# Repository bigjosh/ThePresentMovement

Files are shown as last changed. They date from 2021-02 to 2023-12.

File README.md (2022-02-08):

# The Present Movement
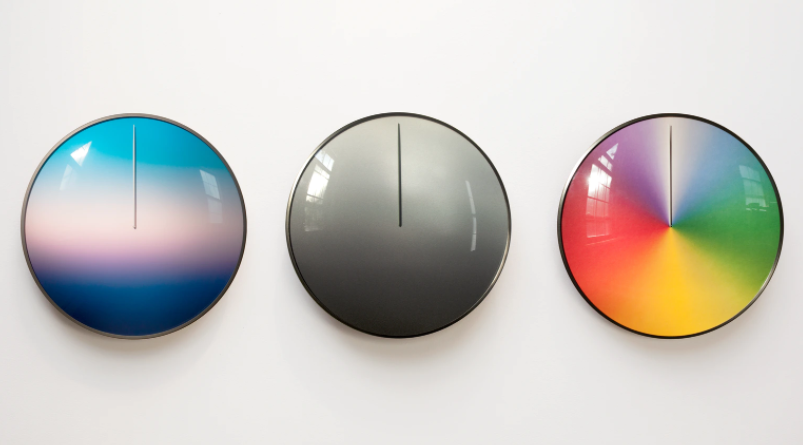
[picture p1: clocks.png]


 Movement for The Present clock from The Present. Kickstarter here...

https://www.kickstarter.com/projects/scottthrift/the-present-day-moon-year

## Features

* Uses proven existing UTS 24h mechanical gearbox gears and lavet motor 
* Can be software configured at programming time for 24h, lunar month, or year period
* Autoset feature lets user automatically move the hand to the correct time position when commissioned in the field 
* Uses a very accurate internal RX8900 real time clock (RTC) chip with temperature compensation that is good to +/-3ppm
* Uses cheap and common ATTINY25 microcontroller (MCU) chip
* Extremely low power - can run for decades or more on 2xAA batteries

## Usage

### Instating 

#### Day mode

Press the button when it is solar noon at the location where the clock will be used. The hand will make a full rotation to indicate that it is now set. For now on, the hand will indicate the current time of day where pointing up to the "noon" position is solar noon and pointing down is solar midnight.

#### Month and year mode

Press the button when you are ready to start using the clock. The hand will make a full rotation and then will continue to the current time. Since the time of lunar month and year are the same every where on Earth, no further input is required. Use in places with non-terran synodic periods is not supported in this version.

##### Southern hemisphere year model

A version of the clock with an inverted face is available on request for use below the equator. 
 
### Manual reset

Should the environment ever become out of sync with the clock hand and it is not possible to correct the environment, you can manually adjust clock hand position using the blue thumb-wheel to bring the two into agreement.  
 
## Theory of operation

### Gearbox 

#### Gearing

We start with a UTS gearbox that rotates an hour shaft once every 24 hours with a "step" once per second (86,400 steps per rotation). We remove the gear that drives the hour shaft and then we glue the now free hour shaft to the minute shaft. This results in an hour shaft that rotates once every 3600 steps. We connect our single hand to this combined hour-minute shaft.

This change in gearing reduces the number of ticks needed for a full rotation by 60 fold. This is good since ticks use power and make noise. This also means we can move to our autoset location 60x faster than we would have been able to if we had left the original gearing in place. 

The only real downside to this modification is reduced torque on the hours shaft, but since we know that the minute shaft must be strong enough to be able to rotate a minute hand, this is not a problem - especially since we no longer have to rotate the extra gears that would have also been driving the hours shaft.

#### Motor

The gearbox is driven by a lavet-type stepper motor. This motor is normally energized with a 1.5V signal across the leads for 50ms which causes the motor to rotate about 1/4 turn. When the coil is de-energized, the motor then rotates an additional 1/4 turn. The combination of these two phases results in a 1/2 turn "step" of the motor. The polarity of the 1.5V across the motor coil is reversed between each alternating step.    

### Ticking

Ticks are periodically generated by the RTC chip. This tick period is programmed into the RTC at start up by the MCU based on the set mode according to this table....

| Mode | 1 Tick every | Period for a 3600 step full rotation | 
| --- | --- | --- |
| Day | 24 seconds | 1 day |
| Moon | 11 minutes 48.734 seconds | 29.53059 days |
| Year | 2 hours 26 minutes 6 seconds | 365.25 days | 

Upon receiving a tick signal from the RTC, the MCU will...

1. Wake from deep low-power sleep
3. Energize the lavet coil (polarity alternates on each phase)
4. Sleep for 50ms to give the lavet rotor a chance to rotate to the intermediate position
5. Wake and de-energize the lavet coil and renable to pull-up
6. Go back to deep sleep to wait for the next tick

This cycle results in two movements of the lavet rotor which result in the hand moving 1/3600th of a rotation around the clock face. This step size is small enough that it is not visible to the naked eye.

#### Pull-up notes

We use the ~INT signal from the clock chip to transmit the ticks to the MCU. The clock chip can only pull this line low, so we use a pull-up resistor in the MCU to keep it high until the clock pulls it low. When the clock does pull it low, it holds it low for 7.813 ms and we can not control this time. To avoid wasting power though the pull-up during this period, we disable the pull-up for the first 16ms of the time when we are waiting for the motor to rotate.

We use the MCU's built-in watchdog timer to wake us up after this initial 16ms snooze, and then again 36ms later when it is time to de-energize the lavet coil. The watchdog timer only has a fixed number of possible timeouts so we picked these values to work around the fixed time periods of the ~INT signal and the lavet rotation. 

#### Polarity

The lavet motor is typically driven by alternating the polarity of a single 1.5V AA battery. We need 2xAA to give us >3V needed to run our chips (both require at least 1.8 volts to run reliably), so we connect one of the motor's leads to the midpoint between the two batteries. We then drive the other lead to either 0V or 3V using an MCU IO pin. This results in the motor seeing either +1.5V or -1.5V across its leads so it is happy. It also means that each battery is only driving the motor on every other step, which further extends battery life.

#### Full speed

The maximum speed the motor can reliably be driven at is 1 step every 100ms (each step consists of an energized and non-energized phase, each about 50ms). This means that it takes about 6 minutes for the hand to rotate all the way around the face at full speed (3600 steps * 100ms/step). We use the MCU's internal watchdog timer for timing these 50ms phases, and that timer is only accurate to +/-10% so the 6 minute time period is only approximate.      

### Autoset for Moon and Year modes

1. The current UTC time is stored in the MCU's EEPROM memory when it is initially programmed in the factory.
2. When it boots up initially after programming, it reads this time from the EEPROM and then uses it to set the RTC. 
3. The MCU then goes into deep sleep while waiting for a button press to wake it up. The RTC now continues to internally keep the current time as long as there is power.
4. When the button is pressed, the MCU wakes up and does a full speed victory lap around the clock face to indicate to give visual feedback to the user. This takes about 6 minutes. 
5. The MCU then sleeps until the next tick from the RTC. 
6. On waking, the MCU asks the RTC for the current UTC time. It uses this value to figure out where it is in the current 3600 step cycle around the clock face it should be
7. The MCU moves the hand to this location at full speed. Since it only takes 6 minutes to get to any hand position, and we know that moon and year ticks happen farther than 6 minutes apart, we do not need to account for time changes that happen while we are autoset positioning the hand.
8. Once the hand reaches the correct location, the MCU sleeps and waits for the next tick from the RTC to move the hand forward one tick. It repeats this until either the battery voltage drops to <1.6V or the heat death of the universe - which ever comes first.

### Autoset for Day modes

Since the hand position in day mode depends on the longitude where the clock happens to find itself on Earth, knowing the UTC time is of no use to us here. Therefore instead, we have the user press the button at solar noon. 

1. The user unpacks the clock and patiently waits until local solar noon. 
2. At the precise moment the sun crosses the meridian, the user anxiously presses the button.  
3. This wakes the MCU, which immediately reads the current UTC time from the RTC and then does a full-speed victory lap (as above) to give visual feedback, coming to rest again at the noon position on the face.
4. The MCU sleeps while it waits for a tick from the RTC (which will come within 24 seconds).
5. The MCU again reads the current time from the RTC and computes how many 1/3600th of a rotation steps are needed to bring the hand to the correct position.
6. The MCU steps the hand at full speed the the lesser of (1) the number of steps needed to get to the correct position, or (2) 200 steps. 
7. The MCU sleeps and waits for the next tick.
8. On waking, the MCU updates the target location forward 1 step and goes back to #6 to continue the race to catch up to the correct position. 

When the hand reaches the correct position, the clock goes into normal run mode where it moves the hand advances one step per tick forever and ever.

The reason we only do 200 steps per tick when trying to catch up is so that we never miss a tick which could give us an offset error. Even though the maximum offset error would be visually undetectable, it would still bother us.       

### Power usage

The ATTINY uses <0.1uA while sleeping and it spends the vast majority of its life sleeping (depending on mode). 

The RX8900 uses on average ~0.7uA at 3V.

Total constant current draw is ~1uA between ticks. 

Each tick additionally consumes an average of ~3.5mA over ~50ms, for a total of about 6.1mW. Remember that each tick only draws on one of the two batteries.  

#### Battery life estimates

##### Day

(1 rotation/day)/(3600 ticks/rotation) = 3600 ticks/day
(3600 ticks/day) * (365 days/year) = 1314000 ticks/year

(1314000 ticks/year) * (50 ms/tick) * (3.5 mA)

(2600 milli amp hour / battery)

(1uA constant draw)

Run time = ~35 years
 
https://frinklang.org/fsp/frink.fsp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

No point in doing the other modes since we are already way past where battery capacity is the limiting factor on lifetime!

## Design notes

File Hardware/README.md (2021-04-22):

# DayMoonYearMovement Hardware

This is the circuit board for the Present's [Day Moon Year Clock](https://www.kickstarter.com/projects/scottthrift/the-present-day-moon-year).

It is basically a brain transplant for an existing standard UCT 24h movement that drives with modes that take a day, a lunar month, or a year to cycle. 

To use this board, you must disassemble the original movement, remove the gear that links the hours and minutes shafts, and then glue those shafts together so that the hours shaft is now driven by the minutes gearing.

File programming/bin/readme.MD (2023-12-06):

# Programming instructions

## Prerequisites

You will need...

1. A windows computer
2. A `USBTiny` compatible programmer (like this [one](https://amzn.to/3AaaWSp))
3. A connector that fits the clock's 6-pin ISP programming port (like [this](https://amzn.to/3nE2BBh) or [this](https://www.sparkfun.com/products/11591))

Note that you can also use a non-Windows computer or a different programmer, but that would require a different procedure.   

## Setup

1. Copy the files from this directory onto the PC 
2. Plug in the programmer to a USB port on the PC
3. Make sure you hear the nice USB noise telling you the drivers installed OK
4. Make sure the little switch on the programmer board is set to `No Power`

## Procedure

1. Install batteries into clock.  
2. Install the hand pointing to 6 o'clock
2. Hold the connector against the clock board like this...

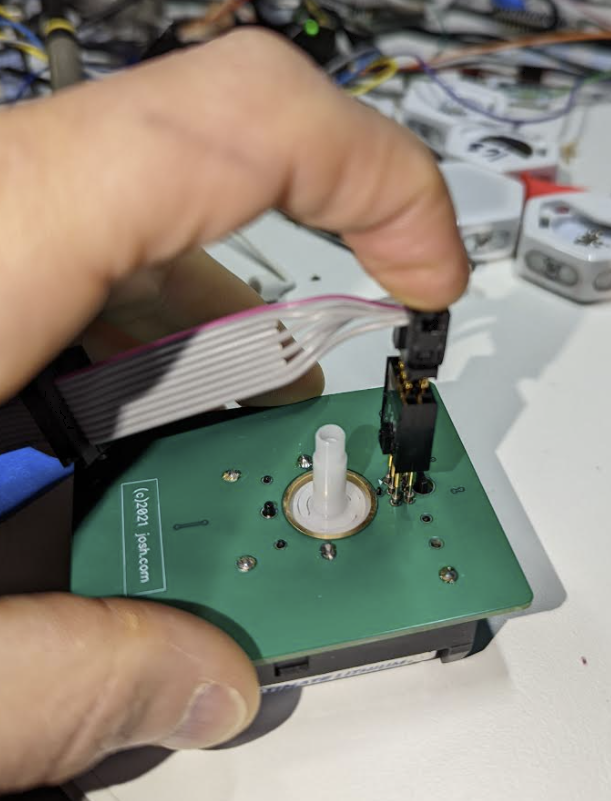
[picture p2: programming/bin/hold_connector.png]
    
1. Double click on the appropriate programming file in the directory (either `day.bat`, `moon.bat`, or `year.bat`)
2. Wait for programming success (see [Problems](#Problems) below if no success)
3. Remove programming connector
4. Push the button on the movement
5. Verify that the hand then rotates from 6 o'clock to noon position
6. Finished!

## Checking

Once the button has been pressed and the hand has completed its 1/2 revolution, the next button press will begin normal ticking. The clock should tick according to this schedule...

| Mode | Full Rotation Period | Tick Every... |
| - | - | - |
| Day | 24 hours | [24 seconds](https://www.wolframalpha.com/input/?i=%28%28day%29+%2F+3600%29+in+seconds) |
| Moon | 1 lunar month [(29.53059 days)](https://en.wikipedia.org/wiki/Lunar_month) | [11 minutes, 48.73411 seconds](https://www.wolframalpha.com/input/?i=%28%28lunar+month%29+%2F+3600%29+in+minutes) |
| Year | 1 solar year [(365.2422 days)](https://www.google.com/search?q=solar+year+in+days)| [2 hours 26 minutes](https://www.wolframalpha.com/input/?i=%28%28year%29+%2F+3600%29+in+minutes) |

## Problems

* Try again a couple of times. If you happen to be unlucky and a tick happens in the middle of the programming cycle that can interrupt the programming.
* Sometimes you need to unplug and replug the programmer into the USB port if the PC has gone to sleep since the last time you used it.
* Make sure all the pins from the programming connector are firmly touching the pads on the clock board.
* Make sure the programming connector is not backwards. The red stripe on the cable should line up with the little white arrow on the moment. 
* Make sure the clock has good batteries installed.
* Makes sure the little switch on the programmer is set to `NO POWER`.
* Try taking the batteries out for a minute and then putting them back in and then program again. Especially if the movement was last programmed in `hour.bat` or `spin.bat` mode since in this case there is likely to be a tick right in the middle of programming.  
* Try using `erase.bat` to quickly erase the chip and see if that works. After erasing, pull the batteries for a minute and then reinstall and try programming again.

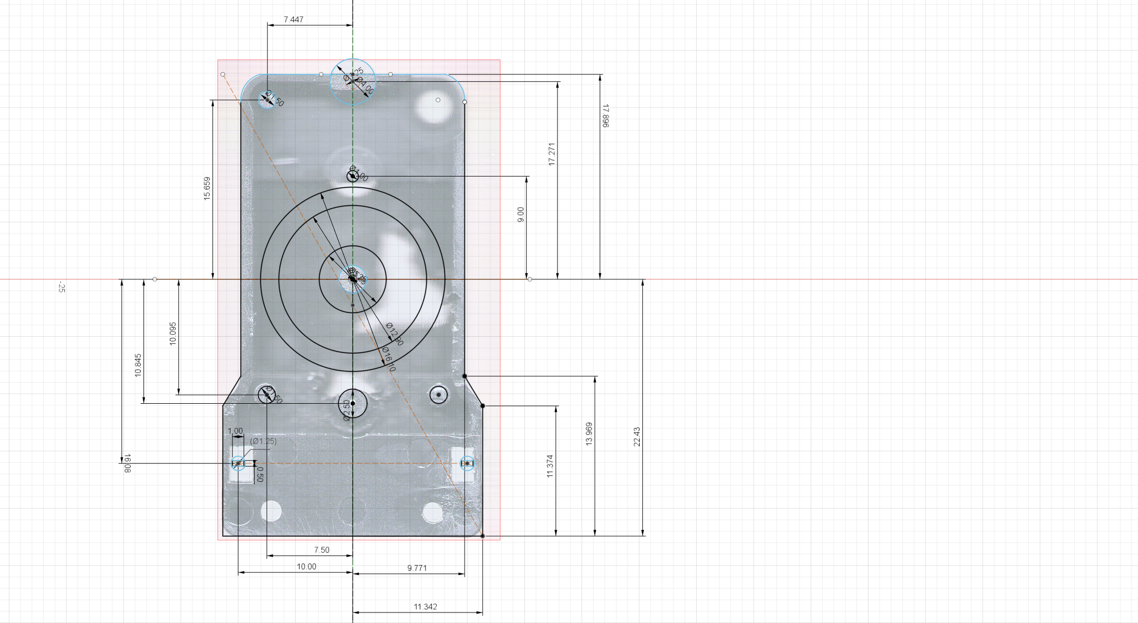
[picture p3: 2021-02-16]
Hardware/Movement demensions.png

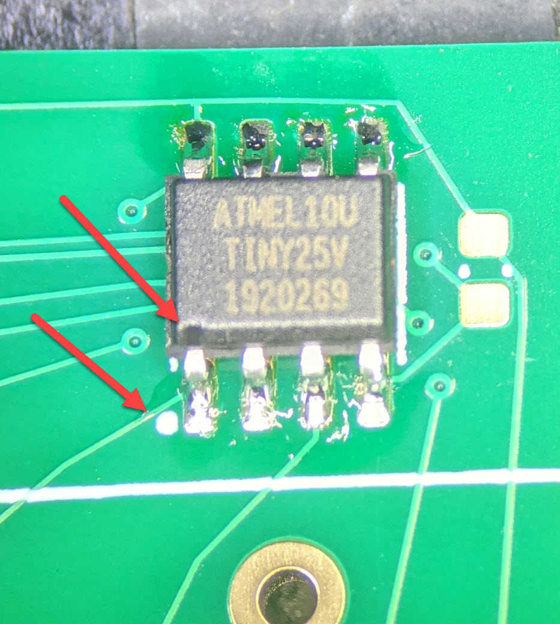
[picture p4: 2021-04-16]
Hardware/Orientation photos/U1 orientation.jpg

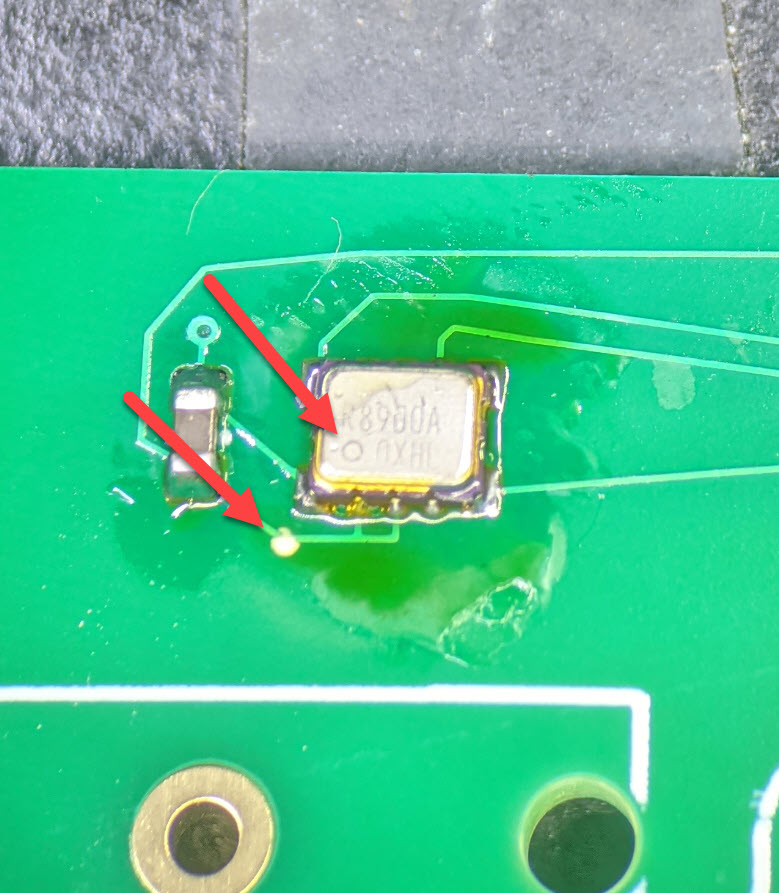
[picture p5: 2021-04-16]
Hardware/Orientation photos/U2 orientation.jpg

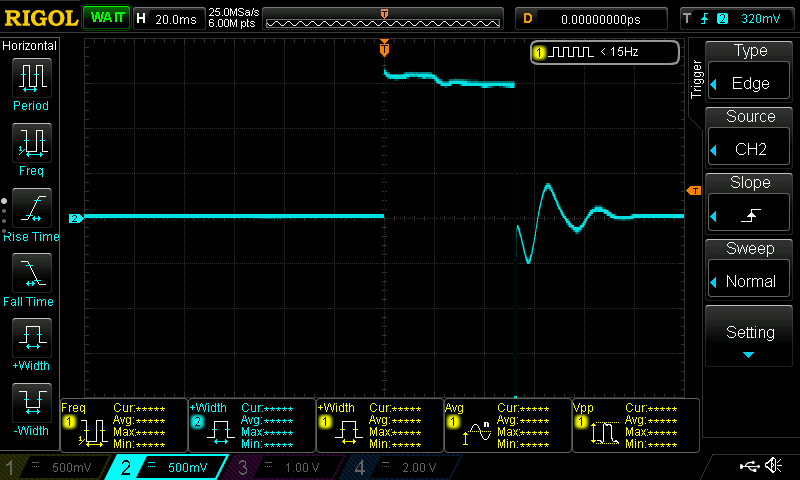
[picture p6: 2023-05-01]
waveforms/new-v-with-coil.png

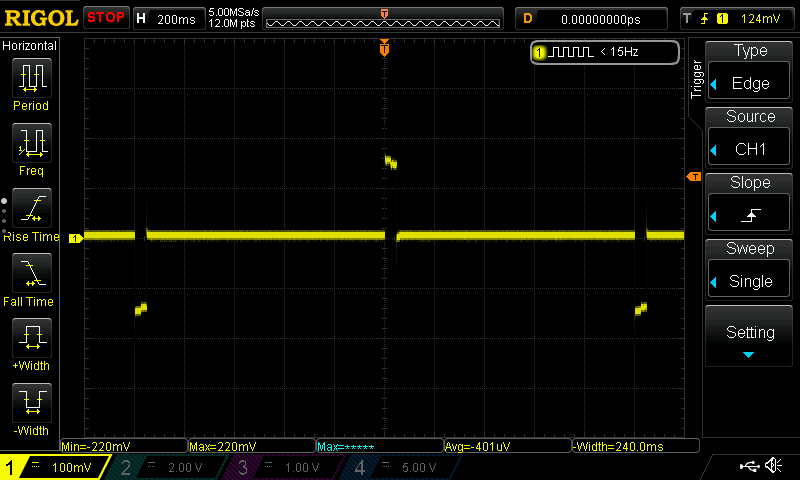
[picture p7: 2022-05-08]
waveforms/Original Movement across motor cycle.png

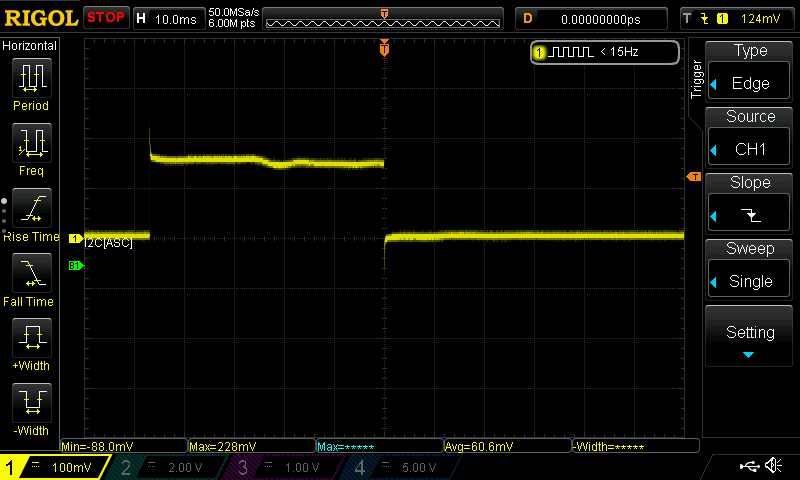
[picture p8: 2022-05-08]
waveforms/Original Movement across motor positive.png

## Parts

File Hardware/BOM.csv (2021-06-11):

# | RefDes | Quantity | Name
1 | BT1 | 1 | KeyStone1087
2 | BT2 | 1 | KeyStone1087
3 | C1 | 1 | C0603C105K3PACTU
4 | C2 | 1 | C0603C105K3PACTU
5 | J1 | 1 | ISP-6-NO-OUTLINE-ALL_ROUND
6 | L1 | 1 | Movement
7 | LOGO | 1 | Logo-Mask
8 | S1 | 1 | TL9320AF400QG
9 | U1 | 1 | ATTINY25-20SSUR
10 | U2 | 1 | RX8900-10SMD

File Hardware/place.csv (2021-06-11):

RefDes | Name | Pattern | Origin X (mm) | Origin Y (mm) | Side | Rotate | Value
BT1 | KeyStone1087 | KeyStone1087 | 19.75 | -11.73 | Top | 90.0
BT2 | KeyStone1087 | KeyStone1087 | -19.75 | -11.73 | Top | 270.0
C1 | C0603C105K3PACTU | CAP_0603_M | -20.32 | 22.86 | Top | 270.0 | 1uF
C2 | C0603C105K3PACTU | CAP_0603_M | 24.13 | 22.86 | Top | 270.0 | 1uF
J1 | ISP-6-NO-OUTLINE-ALL_ROUND | ISP-6-NO-OUTLINE-All-ROUND | 0 | 12.633 | Bottom | 180.0
L1 | Movement | Movement | 0 | 0 | Top | 0.0
LOGO | Logo-Mask | Logo-Mask | 0 | -28.133 | Top | 180.0
S1 | TL9320AF400QG | TL9320AF400QG | 0 | -37.104 | Top | 0.0
U1 | ATTINY25-20SSUR | SOIC8P127_489X599X175L83X41N | 19.75 | 22.86 | Top | 0.0
U2 | RX8900-10SMD | 10-SMD | -16.51 | 22.86 | Top | 90.0

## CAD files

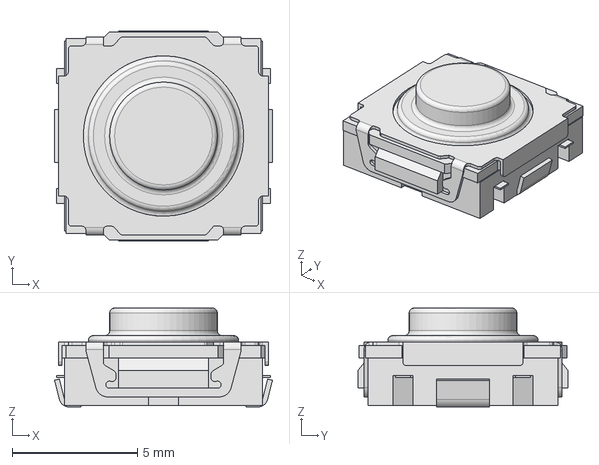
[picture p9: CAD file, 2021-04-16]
Hardware/DipTrace/3D models/TL9320AF400QG.stp
8.70 x 8.40 x 3.95 mm

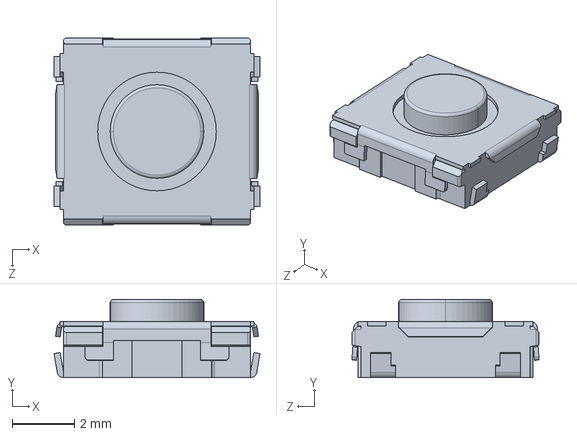
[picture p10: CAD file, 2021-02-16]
Hardware/DipTrace/3D models/EVQQ2-BFKPUY-02W.STEP
6.60 x 2.50 x 6.00 mm

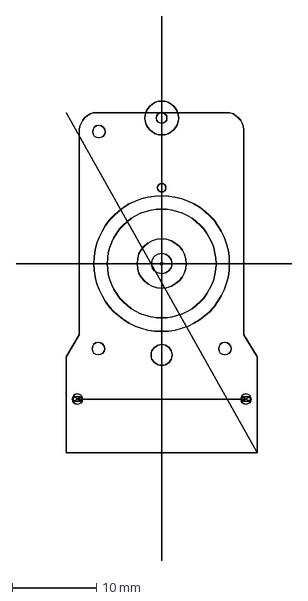
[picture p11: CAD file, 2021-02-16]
Hardware/Movement footprint.dxf
32.7 x 64.6 mm

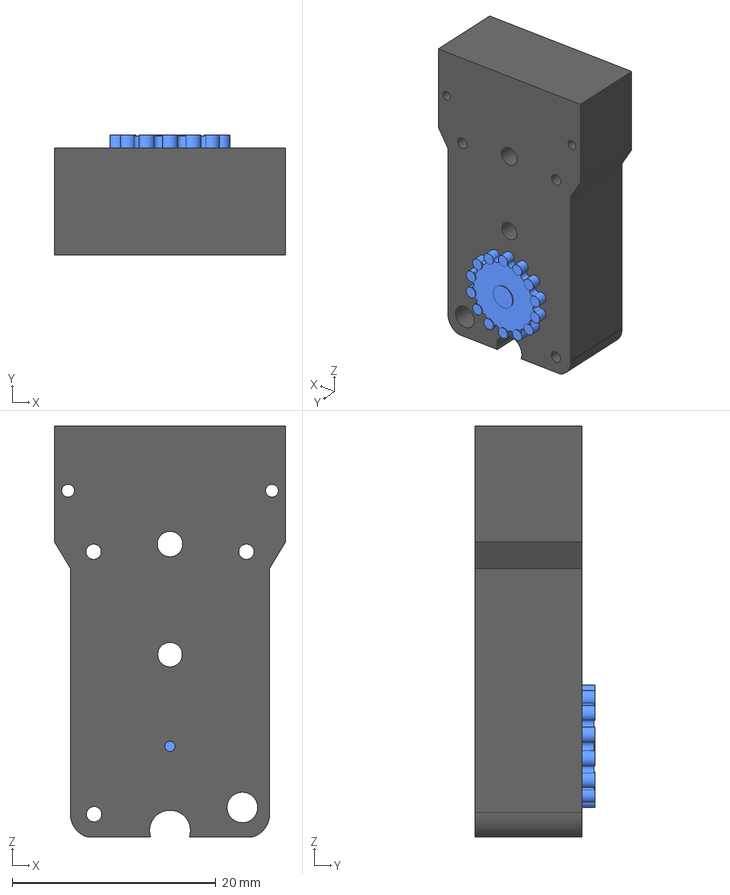
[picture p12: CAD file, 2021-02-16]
Hardware/DipTrace/3D models/Movement.step
22.7 x 11.8 x 40.3 mm

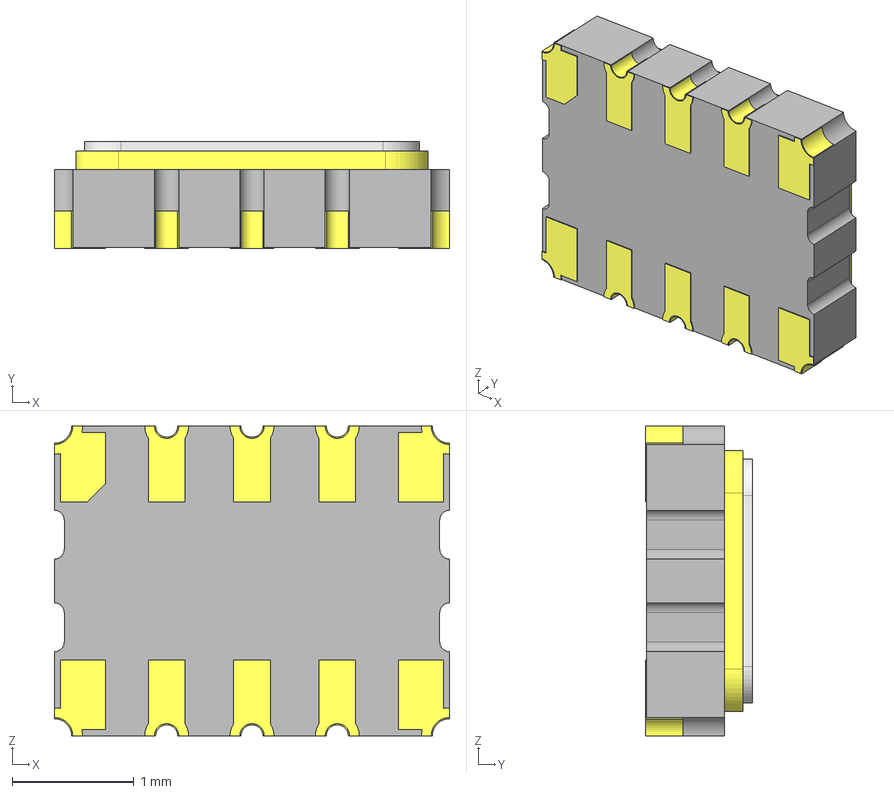
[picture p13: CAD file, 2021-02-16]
Hardware/DipTrace/3D models/RX8900-RA8900CE.stp
3.24 x 0.88 x 2.54 mm
CERAMIC_1_1_2
____-______O__1_6__1_1_2
____-______O__1_5__1_1_2
____-______O__1_10__1_1_2
____-______O__1_7__1_1_2
____-______O__1_3__1_1_2
____-______O__1_4__1_1_2
____-______O__1_1__1_1_2
____-______O__1_2__1_1_2
____-______O__1_9__1_1_2
____-______O__1_8__1_1_2
SRING_1_1_2
LID0001_1_1_2

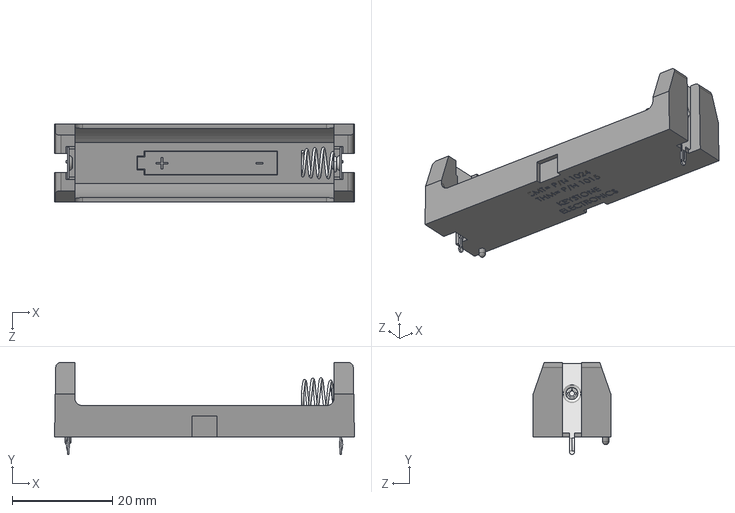
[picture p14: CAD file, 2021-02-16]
Hardware/DipTrace/3D models/keystone-PN1087.STEP
59.9 x 18.4 x 15.5 mm

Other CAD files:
Hardware/Present logo.dxf

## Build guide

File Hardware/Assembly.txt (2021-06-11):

Do place:
U1 
U2
C1
C2
S1

DO NOT PLACE:
BT1
BT2
J1
L1
LOGO

We will provide:
U1
U2

You will procure:
C1
C2
S1

OK TO SUBSTITUTE C1, C2 WITH SUITABLE CAP CER 1UF 25V X5R 0603

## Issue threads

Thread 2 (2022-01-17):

Do a Bresenham's style error track and adjust to cover cases when a rotation period is not exactly divisible by 3600

bigjosh, 2022-01-17:
This comes up with the lunar month which requires (2551443 seconds per rotation/3600 ticks per rotation) = 708.734166667 seconds per tick.

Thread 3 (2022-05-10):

Move /INT to a pin on the ATTINY that is not used in programming

bigjosh, 2022-05-10:
Currently if you get an /INT from the RX8900 in the middle of programming it can interrupt it. This is only a slight hassle since (1) only happens when reprogramming a unit that was already programmed with a short tick time, (2) you can just try again, or (3) you can always just pull the battery to reset the RX8900. But still, easy to completely avoid the issue.

bigjosh, 2023-05-06:
Switch pins with the button. This way, pushing the button will block programming but who cares.

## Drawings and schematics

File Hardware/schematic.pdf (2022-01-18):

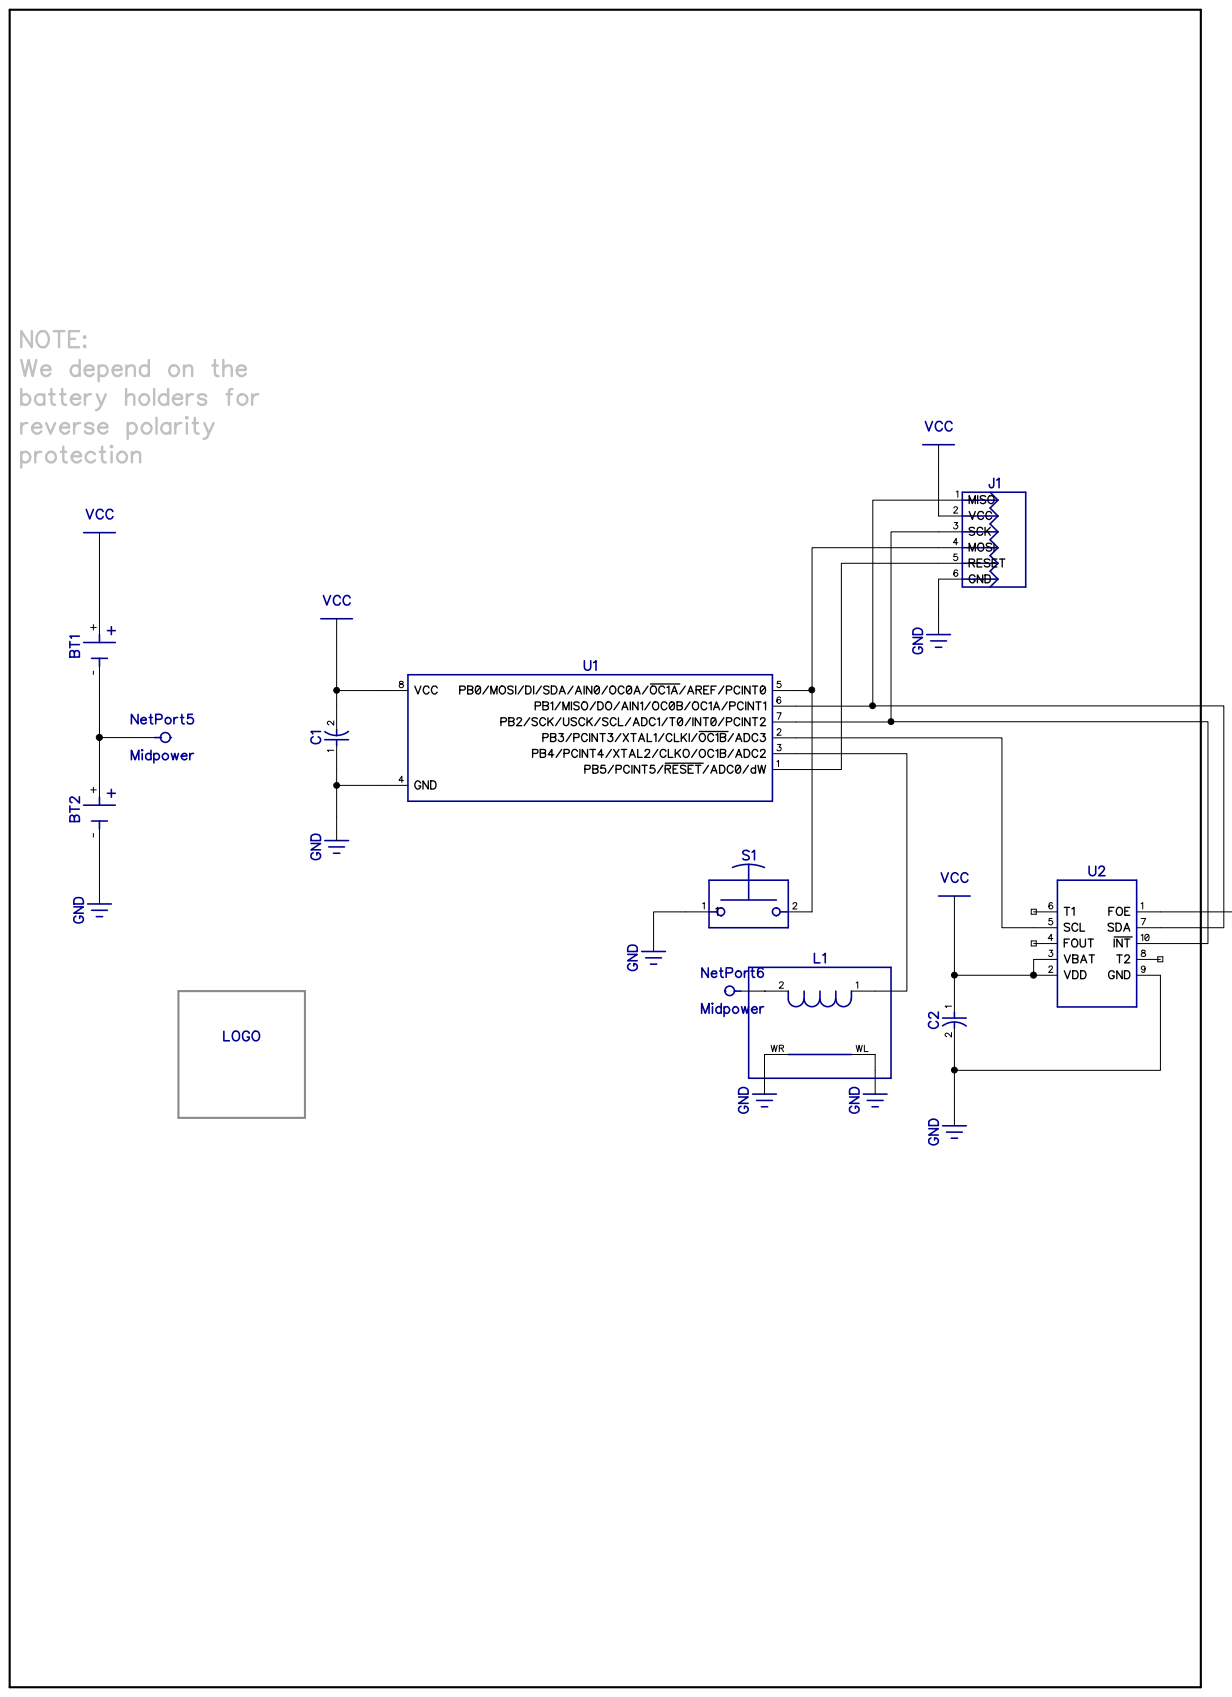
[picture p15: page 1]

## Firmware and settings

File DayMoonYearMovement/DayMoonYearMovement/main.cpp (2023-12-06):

/*
 * DayMoonYearMovement.cpp
 *
 * Created: 2/3/2021 12:04:26 AM
 * Author : josh
 */ 

// Note that this code uses a lambda so requires the "-std=c++11" in compiler options. :/


#include <avr/io.h>
#include <avr/sleep.h>
#include <avr/interrupt.h>
#include <avr/sfr_defs.h>		// _BV()

#include <assert.h>				// static_assert()

#include <avr/eeprom.h>


// Errormode looks like the hand twitching. Count the twitches to see which error.

#define ERRORMODE_COOKIE    2		// Magic cookie not found in EEPROM - EEPROM probably not properly programmed.
#define ERRORMODE_TIMEBASE	3		// If a bad timebase is specified in the EEPROM
#define ERRORMODE_BUTTON	4		// The button was stuck down at power-up

// We use the EEPROM to configure how the movement operates (ie which kind of clock it is in)

// What timebase to use for counting clicks? 
// NOTE: Use timebases < 1 second with care since the constant /INT signal will make it hard to 
// reprogram the unit since it shares the pin with the ISP.

// 0x00 = 4096 Hz - Once per 244.14 us
// 0x01 =   64 Hz - Once per 15.625 ms 
// 0x02 = "Second" update /Once per second 
// 0x03 = "Minute" update /Once per minute 

enum EEPROM_TIMEBASE {
	TB_4096THS	= 0x00,
	TB_64THS	= 0x01,
	TB_1S		= 0x02,
	TB_1M		= 0x03,	
};

const unsigned EEPROM_COOKIE = 0x4C4A;


// We add a magic cookie at the beginning of the EERPOM record so we know it was programmed.
// Could also be used later to version the record format

unsigned getCookieFromEEPROM() {
	
	return eeprom_read_word( (const uint16_t *) 0x0000 );
	
}


unsigned getTimebaseFromEEPROM() {
	
	return eeprom_read_word( (const uint16_t *) 0x0002 );
	
}

// How many clicks of the timebase per tick that gets sent to the MCU over the /INT line?

unsigned getCountFromEEPROM() {
	
	return eeprom_read_word( (const uint16_t *) 0x0004 );
	
}

// How many double ticks should we execute during the start-up button press?
// These ticks give visual feedback that the motor is working.
// We specify half the number of ticks we actually want so we know we always will land on phase A.

unsigned getStartDoubleTicksFromEEPROM() {
	return eeprom_read_word( (const uint16_t *) 0x0006 );		
}


// From the factory, the CLKDIV8 fuse is set, to we are only running at 1Mhz
// This will switch us to full speed 8Mhz, which is fine because we know we will have >3V from the 2xAA batteries. 

void fullSpeedClock() {
	CLKPR = (1<<CLKPCE); // Prescaler enable
	CLKPR = 0; // Clock division factor 1 (8Mhz)
}

void div8Clock() {
	CLKPR = (1<<CLKPCE); // Prescaler enable
	CLKPR = (1<<CLKPS1 || 1<<CLKPS0); // Clock division factor 8 (1Mhz)
}


#define F_CPU 8000000		// Assumes fullSpeedClock() above has been called to get rid of DIV8 that is normally set on power up. This must be defined before the inlcude of SoftI2C.

#include <util/delay.h>
#include <util/delay_basic.h>

#define SETBIT(x,b) ((x) |= _BV(b))
#define CLRBIT(x,b) ((x) &= ~_BV(b))
#define GETBIT(x,b) ((x) & _BV(b))


// *** Hardware connections

// Connections to the RTC (Epson RX8900)

#define RX8900_SCL_PORT PORTB
#define RX8900_SCL_DDR	DDRB
#define RX8900_SCL_BIT	3

#define RX8900_SDA_PORT PORTB
#define RX8900_SDA_DDR	DDRB
#define RX8900_SDA_BIT	1

#define RX8900INT_PORT		PORTB
#define RX8900INT_PIN		PINB
#define RX8900INT_DDR		DDRB
#define RX8900INT_BIT		2
#define RX8900INT_PCMSK		PCINT2

// Define these for the i2c code to see

#define SDA_PORT	RX8900_SDA_PORT
#define SDA_PIN		RX8900_SDA_BIT

#define SCL_PORT	RX8900_SCL_PORT
#define SCL_PIN		RX8900_SCL_BIT

#define	I2C_PULLUP		1					// Use internal pullups for the TWI lines
#define I2C_SLOWMODE	1					// No rush- we are using pullups so give time for them to pull up. 

// We use this not so great i2c code since it does not really matter - we only use it one time on power up and never touch it again
// so not worth rewriting. 

#include "SoftI2C.h"

// Connections to the movement windings (Lavet stepper motor)
// Note that this pin is connected to one end of the motor windings and the other end of the
// windings is connected to the midpoint between the two 1.5V batteries, so driving this pin high
// puts +1.5V on the winding and driving it low puts -1.5V across them. 

// TODO: Put the movement on pin AN0 or AN1 so we can disable the digital input buffer to 
// possibly save power when pin is floating midpoint. 

#define MOVEMENT_PORT	PORTB
#define MOVEMENT_DDR	DDRB
#define MOVEMENT_BIT	4

// Push button

#define BUTTON_PORT		PORTB
#define BUTTON_DDR		DDRB
#define BUTTON_PIN		PINB
#define BUTTON_BIT		0
#define BUTTON_PCMSK	PCINT0			// Set this bit in PCMSK to enable pin change interrupt
#define BUTTON_VECT		PCINT0_vect		// Vector called on pin change interrupt


void disableButton() {

	CLRBIT( PCMSK , BUTTON_PCMSK );	   // Disable change interrupt on this pin. 
	CLRBIT( BUTTON_PORT , BUTTON_BIT); // Disable pull-up
	SETBIT( BUTTON_DDR , BUTTON_BIT ); // Drive low to keep from floating. Pushing button will have no effect and waste no power since it is just connecting pin to ground.
	
}

// Returns true if button is pressed

uint8_t isButtonDown() {
	return !GETBIT( BUTTON_PIN ,  BUTTON_BIT );			// NOTed because pushing button grounds pin
	
}


void movement_mid_h() {
	SETBIT(MOVEMENT_PORT , MOVEMENT_BIT);		// Pull-up on
	SETBIT(MOVEMENT_DDR  , MOVEMENT_BIT);		// Full drive on	
}

void movement_mid_l() {
	SETBIT(MOVEMENT_DDR  , MOVEMENT_BIT);		// Full drive on	
}

// Turn on the pin that drives the movement Lavet motor.
// Phase is 0 or 1 for drive pin low or high 
// Assumes DDR is off and PORT is low (how movement_mid_off() leaves it)

void movement_mid_on( uint8_t phase ) {
	
	if (phase) {
		SETBIT(MOVEMENT_PORT , MOVEMENT_BIT);		// Pull-up on
	}
	
	SETBIT(MOVEMENT_DDR  , MOVEMENT_BIT);		// Full drive high or low depending on PORT as set by phase
		
}

void movement_mid_off() {
	CLRBIT(MOVEMENT_DDR  , MOVEMENT_BIT);		// turn off drive
	CLRBIT(MOVEMENT_PORT , MOVEMENT_BIT);		// turn off Pull-up 
}


// ****** RX8900 stuff
// I would love to break this out into its own file, but it needs the `define`s for the TWI pins
// to be able to use the soft TWI header file, so we would have to put this defines somewhere else
// and they gets too complicated for this very simple project. 


#define RX8900_TWI_ADDRESS_W  0x64	// TWI Write address - RX8900 8.9.5 (datasheet page 29)
#define RX8900_TWI_ADDRESS_R  0x65	// TWI Read address  - RX8900 8.9.5 (datasheet page 29)


#define RX8900_EXTENTION_REG   0x0d


//TE ( Timer Enable ) bit
//This bit controls the start/stop setting for the fixed-cycle timer interrupt function.
//Writing a "1" to this bit specifies starting of the fixed-cycle timer interrupt function (a countdown starts from a
//preset value).
//Writing a "0" to this bit specifies stopping of the fixed-cycle timer interrupt function

#define RX8900_EXTENTION_REG_TE_MASK   _BV(4)		

//TSEL0,1 ( Timer Select 0, 1 ) bits
//The combination of these two bits is used to set the countdown period (source clock) for the fixed-cycle timer
//interrupt function (four settings can be made).
													
#define RX8900_EXTENTION_REG_TSEL1_MASK   _BV(1)		//TE ( Timer Enable ) bit													
#define RX8900_EXTENTION_REG_TSEL0_MASK   _BV(0)		//TE ( Timer Enable ) bit

// These two masks control if the fixed cycle timer values in TC0 and TC1 refer to seconds or minutes

#define RX8900_EXTENTION_REG_TSEL_SEC_MASK	 ( RX8900_EXTENTION_REG_TSEL1_MASK )										// "Second" update / Once per second
#define RX8900_EXTENTION_REG_TSEL_MIN_MASK	 ( RX8900_EXTENTION_REG_TSEL1_MASK |  RX8900_EXTENTION_REG_TSEL0_MASK )		// "Minute" update / Once per minute
#define RX8900_EXTENTION_REG_TSEL_64S_MASK	 ( RX8900_EXTENTION_REG_TSEL0_MASK )										// "1/64ths" update / Once per ~15.6ms
#define RX8900_EXTENTION_REG_TSEL_4096S_MASK ( RX8900_EXTENTION_REG_TSEL0_MASK )										// "1/4096ths" update / Once per ~244us

#define RX8900_TIME_SEC_REG (0)		// Current time seconds

#define RX8900_FLAG_REG        0x0e			

#define RX8900_CONTROL_REG     0x0f

#define RX8900_CONTROL_REG_CSEL1     _BV(7)
#define RX8900_CONTROL_REG_CSEL0     _BV(6)

#define RX8900_CONTROL_REG_RESET     _BV(0)


//CSEL0,1 ( Compensation interval Select 0, 1 ) bits
//The combination of these two bits is used to set the temperature compensation interval.

#define RX8900_CONTROL_REG_TEMPCOMP_2S_MASK     (RX8900_CONTROL_REG_CSEL0)		// (0,1) 2.0s Default
#define RX8900_CONTROL_REG_TIE_MASK				_BV(4)							// TIE ( Timer Interrupt Enable ) bit
																				// When a fixed-cycle timer interrupt event occurs (when the TF bit value changes from "0" to "1"), this bit's value
																				// specifies if an interrupt signal is generated (/INT status changes from Hi-Z to low) or is not generated (/INT status
																				// remains Hi-Z).
																				// When a "1"?is written to this bit, an interrupt signal is generated (/INT status changes from Hi-Z to low) when an
																				// interrupt event is generated.
																				// When a "0"?is written to this bit, no interrupt signal is generated when an interrupt event occurs.

#define RX8900_BACKUP_REG      0x18
#define RX8900_BACKUP_REG      0x18


#define RX8900_BACKUP_REG_VDETOFF_MASK      _BV(3)				// VDETOFF bit (Voltage Detector OFF). This bit controls the voltage detection circuit of the main power supply VDD.
#define RX8900_BACKUP_REG_SWOFF_MASK		_BV(2)				// This bit controls the internal P-MOS switch for preventing back flow.

#define RX8900_BACKUP_REG_DISABLED_VALUE    (RX8900_BACKUP_REG_VDETOFF_MASK)		// This seems to be the recommended config for no backup. Not clear why we leave the switch ON, but that shown in the diagram. 

// How many counts in each fixed cycle timer interrupt. Only 12 bits long. 

#define RX8900_TC0_REG			0x0b	// Fixed-cycle Timer counter 0
#define RX8900_TC1_REG			0x0c	// Fixed-cycle Timer counter 1


void rx8900_reg_set( uint8_t reg , uint8_t v ) {

	i2c_start(RX8900_TWI_ADDRESS_W);		// Write
	i2c_write(reg);
	i2c_write(v);
	i2c_stop();

	
}

void rx8900_ex_reg_set( uint8_t v ) {
	
	// EXTENTION register
	// TEST  0 = Normal
	// WADA  0 = Week alarm (rather than day) (we don't care)
	// USEL  1 = Minute update (rather than second) (we don't use, so pick the slower one?)
	// TE    0 = Stops the fixed cycle interrupt (we don't use)
	// FSEL 10 = 1 Hz FOUT
	// TSEL 11 = 1 minute count down interrupt (we don't use, so pick the slowest one?)

	rx8900_reg_set(RX8900_EXTENTION_REG,v);

}


// Start fixed timer with period minutes whatever last set in set_fixed_time_count()

void rx8900_fixed_timer_start( const unsigned char tsel ) {

	rx8900_reg_set( RX8900_EXTENTION_REG ,  RX8900_EXTENTION_REG_TE_MASK | tsel  ); // Enable fixed timer
	
}

void rx8900_fixed_timer_start_mins() {

	rx8900_reg_set( RX8900_EXTENTION_REG ,  RX8900_EXTENTION_REG_TE_MASK | RX8900_EXTENTION_REG_TSEL_MIN_MASK ); // Enable fixed timer, 1-minute base clock
	
}

// Start fixed timer with period seconds whatever last set in set_fixed_time_count()

void rx8900_fixed_timer_start_secs() {

	rx8900_reg_set( RX8900_EXTENTION_REG , RX8900_EXTENTION_REG_TE_MASK | RX8900_EXTENTION_REG_TSEL_SEC_MASK); // Enable fixed timer, 1-second base clock
	
}


// Start fixed timer with period 1/64th seconds (~15ms)  whatever last set in set_fixed_time_count()

void rx8900_fixed_timer_start_64thsecs() {

	rx8900_reg_set( RX8900_EXTENTION_REG , RX8900_EXTENTION_REG_TE_MASK | RX8900_EXTENTION_REG_TSEL_64S_MASK ); // Enable fixed timer, 15.6ms base clock
	
}


// TODO: Test if the output freq selection in FSELx matters for power if FOUT=0.

void rx8900_fixed_timer_stop() {

	rx8900_reg_set( RX8900_EXTENTION_REG , 0x00 ); // Disable fixed timer
	
}


// How many milliseconds in 1/64th of a second?
#define MS_PER_64TH_S (1000/64)


// Set the RX8900 counts between INT events (MAX = 4195)
// A count can be a second or a minute (and others we don't care about) depending on TSEL bits.
// Count starts when TE bit enabled

void rx8900_fixed_timer_set_count( uint16_t c ) {	
	rx8900_reg_set( RX8900_TC0_REG , c & 0xff );		// Low byte of count value (in seconds)
	rx8900_reg_set( RX8900_TC1_REG , c >> 8 );			// High nibble of count value
}


// When a "1" is written to the TE bit, the fixed-cycle timer countdown starts from the preset value.

void rx8900_fixed_timer_start_seconds( unsigned s ) {

	rx8900_fixed_timer_set_count(s);
	
	rx8900_fixed_timer_start_secs();

}

// When a "1" is written to the TE bit, the fixed-cycle timer countdown starts from the preset value.


void rx8900_fixed_timer_set_minutes( unsigned s ) {
	
	rx8900_fixed_timer_set_count(s);
	
	rx8900_fixed_timer_start_mins();

}



void rx8900_init() {
	
	i2c_init();
}

// Called anytime the RX8900 has seen low voltage (VLF)
// Sets all the control registers to known values
// Clears the flags, so make sure you save any that you need before calling
// stops any running fixed cycle counter
// Does not reset the time counter
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
int main(void)
{
		
	// Switch from bootup 1Mhz to full speed 8Mhz
	// Assumes Vcc>=2.4 
	// https://electronics.stackexchange.com/questions/336718/what-is-the-minimum-voltage-required-to-operate-an-avr-mcu-at-8mhz-clock-speed
	fullSpeedClock();
	
	// *** First set up all pins and pull-ups
	
	SETBIT( BUTTON_PORT , BUTTON_BIT);				// Enable button pull-up. Button connects pin to ground.
	
	SETBIT( RX8900INT_PORT , RX8900INT_BIT );		// Enable pull-up on /INT pin. This is open-drain output on the RX8900 so we need to pull it up with the ATTINY.
	
	
	// TODO: Someday measure the voltage on this pin to get fly back voltage to be able to drive the lavet as a closed loop harmonic stepper. 
	SETBIT( DIDR0 , ADC2D );						// Turn off digital input buffer on the pin connected to the motor windings since this will be floating most of the time. 
	
	
	// TODO: Disable unused stuff with PRR
	
	i2c_init();										// This activates the pull-ups on the i2c SDA and SCL pins. 
	
	_delay_ms(10);		// Give the pull-ups a chance to pull the voltages. Don't use the WDT-based waits because they might get interrupted by the above changing pins. 
	
	//  ALL PINS NOW CONFIGURED FOR PULL-UP
	

	// Get timer settings ready (will start it later)	
	
	// *** Program RTC to generate /INT signal period
	// (also will stop any previously running fixed timer)
	rx8900_setup();


// 	// Test spin
// 
// 	while (1) {
// 		
// 		motorPhaseOn<A>();
// 		_delay_ms(50);
// 		motorPhaseOff<A>();
// 		_delay_ms(50);
// 		
// 		motorPhaseOn<B>();
// 		_delay_ms(50);
// 		motorPhaseOff<B>();
// 		_delay_ms(50);
// 		
// 	}

	// *** Enable sleeping mode
	
	sleep_enable();							// Do once per powerup to enable sleep
	set_sleep_mode(SLEEP_MODE_PWR_DOWN);	// Lowest power, can wake on interrupts (pin change, WDT)
	

	// *** Global interrupt preparation
	
	// Note that all ISRs point to an empty handler - we only use them to wake us and resume form where were went to sleep.
	
	// Enable interrupt on pin change.
	// "Any change on any enabled PCINT[5:0] pin will cause an interrupt."
	// Note that individual pins must also be enabled in the mask
	// Used to wake us every time the fixed-cycle timer pulls /INT low or when the button is pressed (each must be enabled in PCMSK)
	SETBIT( GIMSK  , PCIE );				//When the PCIE bit is set (one) and the I-bit in the Status Register (SREG) is set (one), pin change interrupt is enabled.
		
	
	// Now we will wait for initial button press
	

	SETBIT( PCMSK , BUTTON_PCMSK );	   // Enable change interrupt on the button pin. You must also sei() and enable PCIE in GIMSK to enable all pin change interrupts
	sei();							   // And finally ready to actually enable interrupts. Still need to enable individual pins in the mask as needed.



	// check that our EEPROM is correctly programmed

	if (getCookieFromEEPROM()!=EEPROM_COOKIE) {
		
		errormode(ERRORMODE_COOKIE);
		__builtin_unreachable();
		
	}
	
	

	// Remember that button pin is normally pulled high and pushing it makes it low. 

	// (checks for a stuck down button at startup)
	
	if ( !GETBIT( BUTTON_PIN , BUTTON_BIT )) {
		
		errormode(ERRORMODE_BUTTON);		
		
	}
	
	
		
	// *** Wait for a button press to get us started. This is done at the factory and makes sure the button works.
	
	
	// Wait for button to be in pressed state... (checks for a stuck down button)
	
	while ( GETBIT( BUTTON_PIN , BUTTON_BIT )) {
		
		// sleep until changes and then test again
		sleep_cpu();						// Sleep - we will wake up when button state changes.
		
	}
	
	// If we get here, we know the button is currently pressed.
	
	_delay_ms(50);		// Debounce
	
		
	
	// wait for button to be released. This makes sure the button is not stuck down. 
	
	while ( !GETBIT( BUTTON_PIN , BUTTON_BIT )) {
		
		// sleep until changes and then test again
		sleep_cpu();						// Sleep - we will wake up when button state changes.
		
	}
	
	// No need to debounce here since we around going to do the clock hand spin which takes several seconds.
	

	// Disable the button interrupt just to keep any button bounces or presses from messing up our timing while going around. 
	
	CLRBIT( PCMSK , BUTTON_PCMSK );	   // Disable the interrupt that got us here so we now ignore button changes
	
	
	
	// OK, Now we know the user pushed and released the button so now we can do startup spin test.
	// We will go quickly around the clock face, driven by the RX8900 timer. This tests that the motor works and
	// that the timer works. 

	// We need 3 * 1/64th seconds = ~47ms to get per phase using the 1/64th resolution timer.

	// 47ms per phase = 96ms per tick, so ~2.8 minutes to make a full 360 deg rotation. 
	
	rx8900_fixed_timer_set_count(3);			// 3/64th of a second per tick phase = ~47ms per phase which should be enough time. 
	
	rx8900_fixed_timer_start_64thsecs();		// Start generating pulses on /INT based on the above set counter number of 1/64ths of a second.

	// Note that the interrupt from the INT pin will get enabled inside onNextINTWakeEvent()
		
	// Now quickly spin the hand the number of ticks specified in the EEPROM config.
	// This tests the motor and gives some visual feedback that things are working. 
	
	uint16_t startup_doubleticks = getStartDoubleTicksFromEEPROM();
	
	for( uint16_t i=0; i< startup_doubleticks ; i++ ) {
							
		onNextINTWakeEvent( [](){ motorPhaseOn<A>(); } );
		onNextINTWakeEvent( [](){ motorPhaseOff<A>(); } );
					
		onNextINTWakeEvent( [](){ motorPhaseOn<B>(); } );	
		onNextINTWakeEvent( [](){ motorPhaseOff<B>(); } );		
					
	}
	
	// Turn off the INT pulses that were driving the fast spin to save power.
	
	rx8900_fixed_timer_stop();
	
	
	// OK, now we get ready for the long sleep in the shipping box until the user presses the button again to start the clock. 
	
	
	// Now we wait for user to push button to start real operation. 
		
	SETBIT( PCMSK , BUTTON_PCMSK );	   // Enable change interrupt on the button pin. You must also sei() and enable PCIE in GIMSK to enable all pin change interrupts
	
	
	// Set the fixed timer period count for upcoming free run mode
	// (we will specify if this count is minutes or seconds when we start the fixed timer

	// Minutes in a year
	// https://www.google.com/search?q=%28%281+years%29%2F%283600%29%29+in+minutes
	//rx8900_fixed_timer_set_count(146);
	

	// Remember that button pin is normally pulled high and pushing it makes it low.
	
	// Wait for button to be in pressed state...
	
	while ( GETBIT( BUTTON_PIN , BUTTON_BIT )) {
		
		// sleep until changes and then test again
		sleep_cpu();						// Sleep - we will wake up when button state changes.
		
	}		
	
	// OK, user pressed the button so now we are ready to rock and roll. 

	CLRBIT( PCMSK , BUTTON_PCMSK );			// Disable change interrupt on the button pin- we will never use it again. 
	CLRBIT( BUTTON_PORT , BUTTON_BIT );		// Disable the pull-up
	SETBIT( BUTTON_DDR , BUTTON_BIT );		// Drive button pin low so it will not use any power (we never need to check it again)	
	
	// Now we have to clear out the prescaller and the seconds regs because, despite what the datasheet says, the fixed timer uses these
	// to update the fixed timer counter so if we don't clear these then the first period will be too short by some random amount. :/
	// Luckily we do not use that actual RTC time for anything so we can nonnonchalantly clear these. 	

	rx8900_reset_prescaller();  // We need this to reset the internal prescallers, otherwise first period will be too short by unknown amount.
	rx8900_reg_set( RX8900_TIME_SEC_REG , 0 );		// We also have to clear the seconds register if we want the first period on the minute counter to be correct length


/*
	#warning	
	motorPhaseOn<A>();
	_delay_ms(100);	
	motorPhaseOff<A>();
		
	rx8900_fixed_timer_set_count( 2 );
	rx8900_reset_prescaller();  // We need this to reset the internal prescallers, otherwise first period will be too short by unknown amount. 
	rx8900_reg_set( RX8900_TIME_SEC_REG , 0 );		// We also have to clear the seconds register if we want the first period on the minute counter to be correct length
	rx8900_fixed_timer_start_mins();
	//rx8900_fixed_timer_start( RX8900_EXTENTION_REG_TSEL_SEC_MASK );
	
	motorPhaseOn<B>();	
	_delay_ms(100);	
	motorPhaseOff<B>();	
	
	SETBIT( PCMSK , RX8900INT_PCMSK );				// Enable change interrupt on /INT pin change from RTC.	
	
	while(1) {
		sleep_cpu();
		motorPhaseOn<A>(); 
		_delay_ms(100);
		motorPhaseOff<A>();
		
		sleep_cpu();
		motorPhaseOn<B>(); 
		_delay_ms(100);		
		motorPhaseOff<B>(); 
	}
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

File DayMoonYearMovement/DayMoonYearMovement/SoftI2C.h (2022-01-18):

/* Arduino SoftI2C library. 
 *
 * Version 2.1.2
 *
 * Copyright (C) 2013-2021, Bernhard Nebel and Peter Fleury
 *
 * This is a very fast and very light-weight software I2C-master library 
 * written in assembler. It is based on Peter Fleury's I2C software
 * library: http://homepage.hispeed.ch/peterfleury/avr-software.html
 * Recently, the hardware implementation has been added to the code,
 * which can be enabled by defining I2C_HARDWARE.
 *
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
 * You should have received a copy of the GNU General Public License
 * along with the Arduino I2cMaster Library.  If not, see
 * <http://www.gnu.org/licenses/>.
 */

/* In order to use the library, you need to define SDA_PIN, SCL_PIN,
 * SDA_PORT and SCL_PORT before including this file.  Have a look at
 * http://www.arduino.cc/en/Reference/PortManipulation for finding out
 * which values to use. For example, if you use digital pin 3 (corresponding 
 * to PD3) for SDA and digital pin 13 (corresponding to PB5)
 * for SCL on a standard Arduino,
 * you have to use the following definitions: 
 * #define SDA_PIN 3 
 * #define SDA_PORT PORTD
 * #define SCL_PIN 5
 * #define SCL_PORT PORTB
 *
 * Alternatively, you can define the compile time constant I2C_HARDWARE,
 * in which case the TWI hardware is used. In this case you have to use
 * the standard SDA/SCL pins (and, of course, the chip needs to support
 * this).
 *
 * You can also define the following constants (see also below):
 ' - I2C_PULLUP = 1 meaning that internal pullups should be used 
 * - I2C_CPUFREQ, when changing CPU clock frequency dynamically
 * - I2C_FASTMODE = 1 meaning that the I2C bus allows speeds up to 400 kHz
 * - I2C_SLOWMODE = 1 meaning that the I2C bus will allow only up to 25 kHz 
 * - I2C_NOINTERRUPT = 1 in order to prohibit interrupts while 
 *   communicating (see below). This can be useful if you use the library 
 *   for communicating with SMbus devices, which have timeouts.
 *   Note, however, that interrupts are disabled from issuing a start condition
 *   until issuing a stop condition. So use this option with care!
 * - I2C_TIMEOUT = 0..10000 msec in order to return from the I2C functions
 *   in case of a I2C bus lockup (i.e., SCL constantly low). 0 means no timeout.
 * - I2C_MAXWAIT = 0..32767 number of retries in i2c_start_wait. 0 means never stop.
 */

/* Changelog:
 * Version 2.1
 * - added conditional to check whether it is the right MCU type
 * Version 2.0
 * - added hardware support as well.
 * Version 1.4:
 * - added "maximum retry" in i2c_start_wait in order to avoid lockup
 * - added "internal pullups", but be careful since the option stretches the I2C specs
 * Version 1.3:
 * - added "__attribute__ ((used))" for all functions declared with "__attribute__ ((noinline))"
 *   Now the module is also usable in Arduino 1.6.11+
 * Version 1.2:
 * - added pragma to avoid "unused parameter warnings" (suggestion by Walter)
 * - replaced wrong license file
 * Version 1.1: 
 * - removed I2C_CLOCK_STRETCHING
 * - added I2C_TIMEOUT time in msec (0..10000) until timeout or 0 if no timeout
 * - changed i2c_init to return true if both SDA and SCL are high
 * - changed interrupt disabling so that the previous IRQ state is restored
 * Version 1.0: basic functionality
 */

#ifndef __AVR_ARCH__
#error "Not an AVR MCU! Use 'SlowSoftI2CMaster' library instead of 'SoftI2CMaster'!"
#else

#ifndef _SOFTI2C_H
#define _SOFTI2C_H   1

#include <avr/io.h>
#include <util/twi.h>

#pragma GCC diagnostic push

#pragma GCC diagnostic ignored "-Wunused-parameter"



// Init function. Needs to be called once in the beginning.
// Returns false if SDA or SCL are low, which probably means 
// a I2C bus lockup or that the lines are not pulled up.
bool __attribute__ ((noinline)) i2c_init(void) __attribute__ ((used));

// Start transfer function: <addr> is the 8-bit I2C address (including the R/W
// bit). 
// Return: true if the slave replies with an "acknowledge", false otherwise
bool __attribute__ ((noinline)) i2c_start(uint8_t addr) __attribute__ ((used)); 

// Similar to start function, but wait for an ACK! Will timeout if I2C_MAXWAIT > 0.
bool  __attribute__ ((noinline)) i2c_start_wait(uint8_t addr) __attribute__ ((used));

// Repeated start function: After having claimed the bus with a start condition,
// you can address another or the same chip again without an intervening 
// stop condition.
// Return: true if the slave replies with an "acknowledge", false otherwise
bool __attribute__ ((noinline)) i2c_rep_start(uint8_t addr) __attribute__ ((used));

// Issue a stop condition, freeing the bus.
void __attribute__ ((noinline)) i2c_stop(void) asm("ass_i2c_stop") __attribute__ ((used));

// Write one byte to the slave chip that had been addressed
// by the previous start call. <value> is the byte to be sent.
// Return: true if the slave replies with an "acknowledge", false otherwise
bool __attribute__ ((noinline)) i2c_write(uint8_t value) asm("ass_i2c_write") __attribute__ ((used));


// Read one byte. If <last> is true, we send a NAK after having received 
// the byte in order to terminate the read sequence. 
uint8_t __attribute__ ((noinline)) i2c_read(bool last) __attribute__ ((used));

// If you want to use the TWI hardware, you have to define I2C_HARDWARE to be 1
#ifndef I2C_HARDWARE
#define I2C_HARDWARE 0
#endif

#if I2C_HARDWARE
#ifndef TWDR
#error This chip does not support hardware I2C. Please undefine I2C_HARDWARE
#endif
#endif

// You can set I2C_CPUFREQ independently of F_CPU if you 
// change the CPU frequency on the fly. If you do not define it,
// it will use the value of F_CPU
#ifndef I2C_CPUFREQ
#define I2C_CPUFREQ F_CPU
#endif

// If I2C_FASTMODE is set to 1, then the highest possible frequency below 400kHz
// is selected. Be aware that not all slave chips may be able to deal with that!
#ifndef I2C_FASTMODE
#define I2C_FASTMODE 0
#endif

// If I2C_FASTMODE is not defined or defined to be 0, then you can set
// I2C_SLOWMODE to 1. In this case, the I2C frequency will not be higher 
// than 25KHz. This could be useful for problematic buses with high pull-ups
// and high capacitance.
#ifndef I2C_SLOWMODE
#define I2C_SLOWMODE 0
#endif

// If I2C_PULLUP is set to 1, then the internal pull-up resistors are used.
// This does not conform with the I2C specs, since the bus lines will be
// temporarily in high-state and the internal resistors have roughly 50k.
// With low bus speeds und short buses it usually works, though (hopefully).
#ifndef I2C_PULLUP
#define I2C_PULLUP 0
#endif

// if I2C_NOINTERRUPT is 1, then the I2C routines are not interruptible.
// This is most probably only necessary if you are using a 1MHz system clock,
// you are communicating with a SMBus device, and you want to avoid timeouts.
// Be aware that the interrupt bit is enabled after each call. So the
// I2C functions should not be called in interrupt routines or critical regions.
#ifndef I2C_NOINTERRUPT
#define I2C_NOINTERRUPT 0
#endif
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

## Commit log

2021-02-09 Working with full bore power savings - <1uA running current
    Currently ticks once every 2 seconds. A tick takes ~217 uJ of energy.
2021-02-14 Schematic done?
2021-02-16 First rev PCB done
    [EVQQ2-BFKPUY-02W.STEP, Movement footprint.dxf, Movement.step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]
2021-02-25 Update patterns
    Made gear hole 0.1mm bigger to give more clearance.
    Added 3 copper dots around gear hole to hopefully reduce gap from PCB to gear a bit.
2021-02-27 Clean up PCB
    Use ground plane rather than traces.
    Remove LED and resistor.
    Add pour behind button to make it look nice.
    Move visible button traces. 1212
2021-02-27 Move button area up slightly for appearance
2021-02-27 Remove unneeded via on mid-battery trace.
2021-03-12 PCB bigger hole with nubs, added logo, cleanup.
2021-04-10 Modify shaft hole, add retaining wire for gearbox
    Shaft hole increased and made plated thru.
    Added wire holes to hold the gearbox on.
    [Present logo.dxf]
2021-04-16 Replaced button part. Moved logo to above button.
    [TL9320AF400QG.stp]
2021-06-11 Update with automated assembly files
    [BOM.csv, place.csv]
2022-01-24 Reset RX8900 `/INT` line on load
    [main.cpp]
2022-02-08 Testing code resets RX8900 counters on start
    [main.cpp]
2022-02-08 Update readme with power data
2022-02-10 Fix year.bat and add day.hex
    [main.cpp]
2022-05-08 Add power usage waveforms
2023-05-05 Run CPU in 8Mhz mode.
    Also switched order of enabling/setting the stepper drive pin to try to absorb the inductive kick after a step.
2023-07-15 Fast ticks working with lambdas
    Confirmed that the lambda completely compiles away...
    ```
    asm("nop");
    00000106 NOP No operation
    sleep_cpu();
    00000107 SLEEP Sleep
    CLRBIT( RX8900INT_PORT , RX8900INT_BIT ); // Disable the pull up while the RX8900 pulls ~INT line low for a fixed 7ms. Do this first to minimize power wasted through that resistor.
    00000108 CBI 0x18,2 Clear bit in I/O register
    CLRBIT( PCMSK , RX8900INT_PCMSK ); // Block any interrupt from the INT pin while it is rising again.
    00000109 CBI 0x15,2 Clear bit in I/O register
    SETBIT(MOVEMENT_PORT , MOVEMENT_BIT); // Pull-up on
    0000010A SBI 0x18,4 Set bit in I/O register
    SETBIT(MOVEMENT_DDR , MOVEMENT_BIT); 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
    [main.cpp]
2023-07-15 We do not need to enable/disable WDE just to use the interrupt, so take that out.
2023-07-15 Whole cow crazy typo in `GETBIT()`!
    Lucky to find that one! Also bug in set_fixed_timer_counter() but no effect except making the program a little longer since it had to use divide rather than bit shift.
    [main.cpp]
2023-08-05 Firmware now uses EEPROM for period config, can now show errors by ticking hand
    [main.cpp]
2023-08-05 Change errormode to only repeat the code 5 times to avoid confusing error with startup ticks.
    [main.cpp]
2023-08-05 Remove benign reference to `unused pin`
2023-08-07 Make motor stepping slightly more efficient.
    In the startup spin, we now only use the RX8900 timer to wake us between phases.
    In normal operation, we have condensed two 16ms WDT wake ups into one 32ms.
2023-08-31 Watch for /INT pin to actually rise from pull-up rather than just fixed delay.
    [main.cpp]
2023-12-06 Fixed seconds and minutes fixed timers to have correct first period
    Data sheet is wrong - turns out you need to clear the prescaler for 1st second to be right length and clear the clock seconds for first minute to be correct. :/
    [main.cpp]
2023-12-06 Make program.bat use full 12 bits of timer count to support >256 numbers
    The moon.bat uses 709 seconds as the period so needs more than 8 bits.

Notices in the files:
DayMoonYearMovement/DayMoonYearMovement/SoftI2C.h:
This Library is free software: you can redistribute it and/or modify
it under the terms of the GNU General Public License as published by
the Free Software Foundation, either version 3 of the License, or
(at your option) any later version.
